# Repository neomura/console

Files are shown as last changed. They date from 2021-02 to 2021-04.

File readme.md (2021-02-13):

# neomura/console

Circuit design and shell for home console.

| Link | Description |
| --- | --- |
| [License](./license.md) | MIT License. |
| [Circuit Design](./circuit-design/readme.md) | KiCad files and assembly instructions for the PCB. |
| [Shell](./shell/readme.md) | OpenSCAD modules for the outer shell. |

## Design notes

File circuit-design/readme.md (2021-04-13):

# [neomura/console](../readme.md)/Circuit Design

| Link | Description |
| --- | --- |
| [console.pro](./console.pro) | KiCAD project. |
| [console.sch](./console.sch) | KiCAD schematic. |
| [console.kicad_pcb](./console.kicad_pcb) | KiCAD PCB layout. |
| [Neomura_Console.lib](./Neomura_Console.lib) | KiCAD symbol for pad connector. |
| [Neomura_Console.pretty/BS800L.kicad_mod](./Neomura_Console.pretty/BS800L.kicad_mod) | KiCAD footprint for power/reset switch. |
| [Neomura_Console.pretty/Pad_Connector.kicad_mod](./Neomura_Console.pretty/Pad_Connector.kicad_mod) | KiCAD footprint for pad connector. |
| [Neomura_Console.pretty/RCA_Jack.kicad_mod](./Neomura_Console.pretty/RCA_Jack.kicad_mod) | KiCAD footprint for RCA jack. |

## Bill of materials

Links are included for reference only and are not endorsements.

| Reference | Description | Model No. | Link |
| --- | --- | --- | --- |
| J1 | Cartridge connector (1x15 2.54mm female pin socket) | Unknown | [https://www.aliexpress.com/item/33021040052.html?spm=a2g0s.9042311.0.0.65b74c4dMpBmdG](https://www.aliexpress.com/item/33021040052.html?spm=a2g0s.9042311.0.0.65b74c4dMpBmdG) |
| J2 | 2.1mm PCB-mount DC power jack | Unknown | [https://www.bitsbox.co.uk/index.php?main_page=product_info&cPath=225_232&products_id=1697](https://www.bitsbox.co.uk/index.php?main_page=product_info&cPath=225_232&products_id=1697) |
| J3 | Yellow PCB-mount RCA jack | AV-8.4-5 (yellow) | [https://www.aliexpress.com/item/4000661766823.html?spm=a2g0s.9042311.0.0.102e4c4dDtr353](https://www.aliexpress.com/item/4000661766823.html?spm=a2g0s.9042311.0.0.102e4c4dDtr353) |
| J4 | White PCB-mount RCA jack | AV-8.4-5 (white)  | [https://www.aliexpress.com/item/4000661766823.html?spm=a2g0s.9042311.0.0.102e4c4dDtr353](https://www.aliexpress.com/item/4000661766823.html?spm=a2g0s.9042311.0.0.102e4c4dDtr353) |
| J5 | Red PCB-mount RCA jack | AV-8.4-5 (red) | [https://www.aliexpress.com/item/4000661766823.html?spm=a2g0s.9042311.0.0.102e4c4dDtr353](https://www.aliexpress.com/item/4000661766823.html?spm=a2g0s.9042311.0.0.102e4c4dDtr353) |
| J6/J7/J8/J9 | 90-degree SNES controller jack | Unknown | [https://www.aliexpress.com/item/32828768824.html?spm=a2g0s.9042311.0.0.102e4c4dh9cZSi](https://www.aliexpress.com/item/32828768824.html?spm=a2g0s.9042311.0.0.102e4c4dh9cZSi) |
| SW1 | 8x8mm latching button | BS800L | [https://www.amazon.co.uk/gp/product/B01KJHR3W6/ref=ppx_yo_dt_b_asin_title_o01_s00?ie=UTF8&psc=1](https://www.amazon.co.uk/gp/product/B01KJHR3W6/ref=ppx_yo_dt_b_asin_title_o01_s00?ie=UTF8&psc=1) |
| SW2 | 8x8mm momentary button | Unknown | [https://www.amazon.co.uk/gp/product/B00TX5K07G/ref=ppx_yo_dt_b_asin_title_o00_s00?ie=UTF8&psc=1](https://www.amazon.co.uk/gp/product/B00TX5K07G/ref=ppx_yo_dt_b_asin_title_o00_s00?ie=UTF8&psc=1) |
| R1 | 4.7K resistor | Unknown | [https://www.bitsbox.co.uk/index.php?main_page=product_info&cPath=83_84_85&products_id=2561](https://www.bitsbox.co.uk/index.php?main_page=product_info&cPath=83_84_85&products_id=2561) |
| D1 | Green 5x2x8 rectangular LED | Unknown | [https://www.bitsbox.co.uk/index.php?main_page=product_info&cPath=172_177&products_id=1343](https://www.bitsbox.co.uk/index.php?main_page=product_info&cPath=172_177&products_id=1343) |

A USB A to 2.1mm DC 5V cable such as [https://www.amazon.co.uk/gp/product/B07SR1SGXQ/ref=ppx_yo_dt_b_asin_title_o05_s00?ie=UTF8&psc=1](https://www.amazon.co.uk/gp/product/B07SR1SGXQ/ref=ppx_yo_dt_b_asin_title_o05_s00?ie=UTF8&psc=1) can be used to power the console from a USB power supply.

9.5x4mm self-adhestive feet such as [https://www.bitsbox.co.uk/index.php?main_page=product_info&cPath=185_190&products_id=1418](https://www.bitsbox.co.uk/index.php?main_page=product_info&cPath=185_190&products_id=1418) can be applied to the pockets in the unside of the shell.

### Possible substitutions

#### SW2

SW2 has identical external dimensions to SW1.  It is possible to convert a BS800L to a momentary switch as the momentary variant appears to be somewhat uncommon:

- Use a spudger or pair of tweasers to prise the tabs on opposite sides away and lift the top half of the body away - these tabs are usually white if the bottom half is black or vice versa.
- The blue plunger should now lift out.  Note that there is a small spring underneath it, and a metal contact on either side of it.  These may fall off.
- At the bottom of the bottom half of the body is a small piece of bent wire which is responsible for the latching motion (you can see this through the square cutout in the bottom of the switch).  You should be able to remove this using tweasers.
- Replace the blue plunger, putting the spring back in and pressing the metal contacts back on if they fell off.
- Replace the top half of the body.  The tabs should click back into place.

The button should now press like before, but not latch.  You can check that the switch still works using a multimeter, looking from the bottom:

```
.-----.
|1 3 2|
|   []|
|6 4 5|
'-----'
```

When the switch **is not** pressed, leads 1 and 3, and 6 and 4 **should** be connected.  Leads 3 and 2, and 4 and 5 **should not** be connected.

When the switch **is** pressed, leads 3 and 2, and 4 and 5 **should** be connected.  Leads 1 and 3, and 6 and 4 **should not** be connected.

SW2 could also be omitted entirely at the cost of losing reset functionality (removal of the hole in the top half of the shell is recommended if this is done).

#### D1

The LED can be replaced or omitted entirely - just ensure that R1 is adjusted (or omitted) as appropriate.  Removal of the hole in the top half of the shell is recommended if the LED is omitted.

## Assembly instructions

- Solder R1 and J1, and clip leads.  Ensure that J1's underside is flat against the PCB (no gap, and upright) otherwise the cartridge may not fit.
- Place the top half of the shell upside down.
- Place J2, J3, J4, J5, J6, J7, J8, J9 and D1 into their respective cavities in the top half of the shell.
- Place the PCB logo side down onto the leads of the placed components.
- Solder J2, J3, J4, J5, J6, J7, J8, J9 and D1, and clip leads.
- Press-fit the bottom half of the shell in place.

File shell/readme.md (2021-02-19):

# [neomura/console](../readme.md)/Shell

| Link | Description |
| --- | --- |
| [bottom.scad](./bottom.scad) | OpenSCAD model for the bottom half of the shell. |
| [button-measurements.scad](./button-measurements.scad) | OpenSCAD module describing buttons. |
| [dc-jack-measurements.scad](./dc-jack-measurements.scad) | OpenSCAD module describing DC jacks. |
| [foot-measurements.scad](./foot-measurements.scad) | OpenSCAD module describing feet. |
| [label-measurements.scad](./label-measurements.scad) | OpenSCAD module describing labels. |
| [led-measurements.scad](./led-measurements.scad) | OpenSCAD module describing LEDs. |
| [outer-measurements.scad](./ouoter-measurements.scad) | OpenSCAD module describing the outer perimeter. |
| [pad-connector-measurements.scad](./pad-connector-measurements.scad) | OpenSCAD module describing pad connectors. |
| [pcb-measurements.scad](./pcb-measurements.scad) | OpenSCAD module describing the PCB. |
| [peg-measurements.scad](./peg-measurements.scad) | OpenSCAD module describing retaining pegs. |
| [power-button.scad](./power-button.scad) | OpenSCAD model for the power button. |
| [rca-jack-measurements.scad](./rca-jack-measurements.scad) | OpenSCAD module describing RCA jacks. |
| [reset-button.scad](./reset-button.scad) | OpenSCAD model for the reset button. |
| [resistor-measurements.scad](./rca-jack-measurements.scad) | OpenSCAD module describing resistors. |
| [top.scad](./top.scad) | OpenSCAD model for the top half of the shell. |
| [unsplit.scad](./unsplit.scad) | OpenSCAD module for the shell as a whole, unsplit into top and bottom halves. |

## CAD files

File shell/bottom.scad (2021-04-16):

use <../submodules/neomura/cartridge/measurements.scad>;
use <../submodules/neomura/cartridge/slot/vertical/solder-joint-cutout.scad>;
use <pad-connector-measurements.scad>;
use <pcb-measurements.scad>;
use <outer-measurements.scad>;
use <rca-jack-measurements.scad>;
use <unsplit.scad>;
use <resistor-measurements.scad>;
use <led-measurements.scad>;
use <dc-jack-measurements.scad>;
use <button-measurements.scad>;
use <foot-measurements.scad>;
use <label-measurements.scad>;
use <slot-measurements.scad>;

intersection() {
  difference() {
    // The main block.
    translate([
      console_outer_left(),
      console_outer_near(),
      0,
    ]) {
      cube([
        - console_outer_left() + console_outer_right(),
        - console_outer_near() + console_outer_far(),
        console_pcb_top() + console_rca_jack_position(),
      ]);
    };

    // Cutout for PCB.
    translate([
      console_pcb_left() - cartridge_pcb_tolerance(),
      console_pcb_near() - cartridge_pcb_tolerance(),
      console_pcb_bottom(),
    ]) {
      cube([
        cartridge_pcb_tolerance() - console_pcb_left() + console_pcb_right() + cartridge_pcb_tolerance(),
        cartridge_pcb_tolerance() - console_pcb_near() + console_pcb_far() + cartridge_pcb_tolerance(),
        cartridge_pcb_tolerance() + cartridge_pcb_thickness() + cartridge_pcb_tolerance() + console_pcb_to_top(),
      ]);
    };

    // Cutouts for feet.
    linear_extrude(console_foot_embed()) {
      translate([
        console_outer_left() + console_foot_margin() + console_foot_diameter() / 2,
        console_outer_near() + console_foot_margin() + console_foot_diameter() / 2,
      ]) {
        circle(
          d = console_foot_tolerance() + console_foot_diameter() + console_foot_tolerance(),
          $fn = console_foot_sides()
        );
      };

      translate([
        console_outer_right() - console_foot_margin() - console_foot_diameter() / 2,
        console_outer_near() + console_foot_margin() + console_foot_diameter() / 2,
      ]) {
        circle(
          d = console_foot_tolerance() + console_foot_diameter() + console_foot_tolerance(),
          $fn = console_foot_sides()
        );
      };

      translate([
        console_outer_left() + console_foot_margin() + console_foot_diameter() / 2,
        console_outer_far() - console_foot_margin() - console_foot_diameter() / 2,
      ]) {
        circle(
          d = console_foot_tolerance() + console_foot_diameter() + console_foot_tolerance(),
          $fn = console_foot_sides()
        );
      };

      translate([
        console_outer_right() - console_foot_margin() - console_foot_diameter() / 2,
        console_outer_far() - console_foot_margin() - console_foot_diameter() / 2,
      ]) {
        circle(
          d = console_foot_tolerance() + console_foot_diameter() + console_foot_tolerance(),
          $fn = console_foot_sides()
        );
      };
    };

    // Solder joint cutouts.
    translate([
      0,
      0,
      console_pcb_bottom() - console_pcb_to_bottom(),
    ]) {
      linear_extrude(console_pcb_to_bottom() + cartridge_pcb_tolerance() + cartridge_pcb_thickness()) {
        translate([
          console_slot_x(),
          console_slot_y(),
        ]) {
          cartridge_slot_vertical_solder_joint_cutout();
        };

        for (pad_position = console_pad_connector_positions()) {
          translate([
            pad_position[0],
            pad_position[1],
          ]) {
            rotate(pad_position[2]) {
              translate([0, cartridge_wall_thickness(), 0]) {
                translate([
                  - cartridge_loose_fit_tolerance() + console_pad_connector_terminals_width() / -2,
                  - console_pad_connector_terminals_length() - console_pad_connector_length() - cartridge_loose_fit_tolerance(),
                ]) {
                  square([
                    cartridge_loose_fit_tolerance() + console_pad_connector_terminals_width() + cartridge_loose_fit_tolerance(),
                    console_pad_connector_terminals_length(),
                  ]);
                };

                translate([
                  console_pad_connector_peg_spacing() / -2,
                  - console_pad_connector_peg_inset(),
                ]) {
                  circle(
                    d = console_pad_connector_peg_diameter(),
                    $fn = console_pad_connector_peg_sides()
                  );
                };

                translate([
                  console_pad_connector_peg_spacing() / 2,
                  - console_pad_connector_peg_inset(),
                ]) {
                  circle(
                    d = console_pad_connector_peg_diameter(),
                    $fn = console_pad_connector_peg_sides()
                  );
                };
              };
            };
          };
        };

        for (button_position = console_button_positions()) {
          translate([button_position[0], button_position[1]]) {
            rotate(button_position[2]) {
              translate([
                - (cartridge_pad_spacing() / 2 + console_button_body_width() + cartridge_pad_spacing() / 2) / 2,
                - (cartridge_pad_spacing() / 2 + console_button_body_length() + cartridge_pad_spacing() / 2) / 2,
              ]) {
                square([
                  cartridge_pad_spacing() / 2 + console_button_body_width() + cartridge_pad_spacing() / 2,
                  cartridge_pad_spacing() / 2 + console_button_body_length() + cartridge_pad_spacing() / 2,
                ]);
              };
            };
          };
        };

        for (led_position = console_led_positions()) {
          translate([led_position[0], led_position[1]]) {
            rotate(led_position[2]) {
              translate([
                - console_led_width() / 2,
                - console_led_length() / 2,
              ]) {
                square([console_led_width(), console_led_length()]);
              };
            };
          };
        };

        for (resistor_position = console_resistor_positions()) {
          translate([resistor_position[0], resistor_position[1]]) {
            rotate(resistor_position[2]) {
              translate([
                - console_resistor_width() / 2,
                - console_resistor_length() / 2,
              ]) {
                square([
                  console_resistor_width(),
                  console_resistor_length(),
                ]);
              };
            };
          };
        };

        for (dc_jack_position = console_dc_jack_positions()) {
          translate([dc_jack_position[0], dc_jack_position[1]]) {
            rotate(dc_jack_position[2]) {
              for (pad_position = console_dc_jack_pad_positions()) {
                translate(pad_position) {
                  square(console_dc_jack_pad_diameter(), center = true);
                };
              };
            };
          };
        };

        for (rca_jack_position = console_rca_jack_positions()) {
          translate([rca_jack_position[0], rca_jack_position[1]]) {
            rotate(rca_jack_position[2]) {
              translate([
                - cartridge_loose_fit_tolerance() -console_rca_jack_body_width() / 2,
                -console_rca_jack_pocket_length(),
              ]) {
                square([
                  cartridge_loose_fit_tolerance() + console_rca_jack_body_width() + cartridge_loose_fit_tolerance(),
                  console_rca_jack_pocket_length() + cartridge_loose_fit_tolerance(),
                ]);
              };

              for (pad_position = console_rca_jack_pad_positions()) {
                translate(pad_position) {
                  square(console_rca_jack_pad_diameter(), center = true);
                };
              };
            };
          };
        };
      };
    };

    // Label.
    linear_extrude(cartridge_engraving_depth()) {
      hull() {
        translate([
          console_label_width() / 2 - console_label_radius(),
          (console_outer_near() + console_outer_far() + console_label_height()) / 2 - console_label_radius(),
        ]) {
          circle(
            r = console_label_radius(),
            $fn = cartridge_engraving_sides()
          );
        };

        translate([
          - console_label_width() / 2 + console_label_radius(),
          (console_outer_near() + console_outer_far() + console_label_height()) / 2 - console_label_radius(),
        ]) {
          circle(
            r = console_label_radius(),
            $fn = cartridge_engraving_sides()
          );
        };

        translate([
          console_label_width() / 2 - console_label_radius(),
          (console_outer_near() + console_outer_far() - console_label_height()) / 2 + console_label_radius(),
        ]) {
          circle(
            r = console_label_radius(),
            $fn = cartridge_engraving_sides()
          );
        };
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

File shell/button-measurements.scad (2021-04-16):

use <../submodules/neomura/cartridge/measurements.scad>;
use <pad-connector-measurements.scad>;

function console_button_throw() = 2.3;

function console_button_stub_width() = 3 + cartridge_loose_fit_tolerance() * 2;
function console_button_stub_length() = 2 + cartridge_loose_fit_tolerance() * 2;
function console_button_stub_height() = 2.5 + cartridge_loose_fit_tolerance();

function console_button_pixel_size() = cartridge_logo_height() / 7;
function console_button_pixel_push() = 0.075;

function console_button_length() = console_button_pixel_size() + cartridge_engraving_radius() + cartridge_logo_height() + cartridge_engraving_radius() + console_button_pixel_size();
function console_button_width() = console_button_length();
function console_button_height() = console_button_stub_height() + cartridge_wall_thickness() + console_button_throw();

function console_button_lip_width() = cartridge_wall_thickness();
function console_button_lip_height() = cartridge_wall_thickness();

function console_button_body_width() = 8.125;
function console_button_body_length() = 8.125;
function console_button_body_height() = 8;

function console_button_tolerance() = 0.3;

function console_button_positions() = [
  [
    console_pad_connector_positions()[0][0],
    0,
    0,
  ],
  [
    console_pad_connector_positions()[3][0],
    0,
    0,
  ],
];

module console_button() {
  difference() {
      linear_extrude(console_button_height()) {
        hull() {
          translate([
            console_button_width() / 2 - console_button_pixel_size() - cartridge_engraving_radius(),
            console_button_length() / 2 - console_button_pixel_size() - cartridge_engraving_radius(),
          ]) {
            circle(
              r = cartridge_engraving_radius() + console_button_pixel_size(),
              $fn = cartridge_engraving_sides()
            );
          };

          translate([
            console_button_width() / 2 - console_button_pixel_size() - cartridge_engraving_radius(),
            - console_button_length() / 2 + console_button_pixel_size() + cartridge_engraving_radius(),
          ]) {
            circle(
              r = cartridge_engraving_radius() + console_button_pixel_size(),
              $fn = cartridge_engraving_sides()
            );
          };

          translate([
            - console_button_width() / 2 + console_button_pixel_size() + cartridge_engraving_radius(),
            console_button_length() / 2 - console_button_pixel_size() - cartridge_engraving_radius(),
          ]) {
            circle(
              r = cartridge_engraving_radius() + console_button_pixel_size(),
              $fn = cartridge_engraving_sides()
            );
          };

          translate([
            - console_button_width() / 2 + console_button_pixel_size() + cartridge_engraving_radius(),
            - console_button_length() / 2 + console_button_pixel_size() + cartridge_engraving_radius(),
          ]) {
            circle(
              r = cartridge_engraving_radius() + console_button_pixel_size(),
              $fn = cartridge_engraving_sides()
            );
          };
        };
      };

    translate([
      0,
      0,
      console_button_height() - cartridge_engraving_depth(),
    ]) {
      linear_extrude(cartridge_engraving_depth()) {
        difference() {
          hull() {
            translate([
              console_button_width() / 2 - console_button_pixel_size() - cartridge_engraving_radius(),
              console_button_length() / 2 - console_button_pixel_size() - cartridge_engraving_radius(),
            ]) {
              circle(
                r = cartridge_engraving_radius(),
                $fn = cartridge_engraving_sides()
              );
            };

            translate([
              console_button_width() / 2 - console_button_pixel_size() - cartridge_engraving_radius(),
              - console_button_length() / 2 + console_button_pixel_size() + cartridge_engraving_radius(),
            ]) {
              circle(
                r = cartridge_engraving_radius(),
                $fn = cartridge_engraving_sides()
              );
            };

            translate([
              - console_button_width() / 2 + console_button_pixel_size() + cartridge_engraving_radius(),
              console_button_length() / 2 - console_button_pixel_size() - cartridge_engraving_radius(),
            ]) {
              circle(
                r = cartridge_engraving_radius(),
                $fn = cartridge_engraving_sides()
              );
            };

            translate([
              - console_button_width() / 2 + console_button_pixel_size() + cartridge_engraving_radius(),
              - console_button_length() / 2 + console_button_pixel_size() + cartridge_engraving_radius(),
            ]) {
              circle(
                r = cartridge_engraving_radius(),
                $fn = cartridge_engraving_sides()
              );
            };
          };

          children();
        };
      };
    };

    translate([
      console_button_stub_width() / -2,
      console_button_stub_length() / -2,
      0,
    ]) {
      cube([
        console_button_stub_width(),
        console_button_stub_length(),
        console_button_stub_height(),
      ]);
    };
  };
};

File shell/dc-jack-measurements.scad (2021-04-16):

use <../submodules/neomura/cartridge/measurements.scad>;
use <pad-connector-measurements.scad>;

function console_dc_jack_body_width() = 9;
function console_dc_jack_body_length() = 13.8;
function console_dc_jack_body_height() = 10.2;

function console_dc_jack_face_height() = 11;
function console_dc_jack_face_thickness() = 2.9;

function console_dc_jack_diameter() = 8.35;
function console_dc_jack_position() = 6.6;
function console_dc_jack_sides() = 48;

function console_dc_jack_positions() = [
  [
    console_pad_connector_positions()[0][0],
    23.0825,
    180,
  ],
];

function console_dc_jack_pad_diameter() = 3.5;
function console_dc_jack_pad_positions() = [
  [0, 7.7],
  [4.75, 10.72],
  [0, 13.7],
];

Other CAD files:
shell/foot-measurements.scad
shell/foot.scad
shell/label-measurements.scad
shell/led-measurements.scad
shell/outer-measurements.scad
shell/pad-connector-measurements.scad
shell/pcb-measurements.scad
shell/power-button.scad
shell/rca-jack-measurements.scad
shell/reset-button.scad
shell/resistor-measurements.scad
shell/slot-measurements.scad
shell/top.scad
shell/unsplit.scad

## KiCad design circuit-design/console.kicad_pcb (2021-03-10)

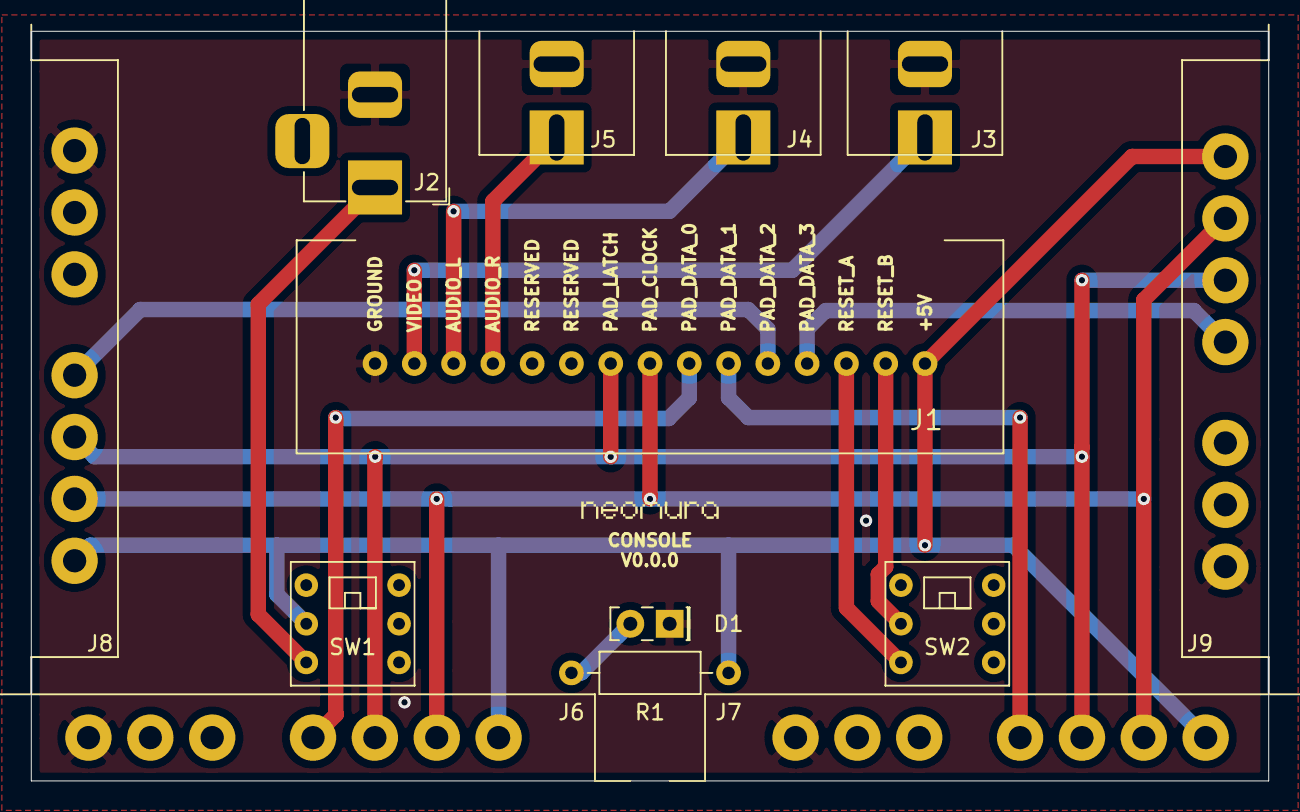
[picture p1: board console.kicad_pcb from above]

Board: 2 copper layers, 80.0 x 48.5 mm, 14 parts (0 on the bottom side), 15 nets.

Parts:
D1: LED; LED_Rectangular_W5.0mm_H2.0mm
J1: CARTRIDGE; Slot-Vertical
J2: POWER; BarrelJack_Horizontal
J3: VIDEO (YELLOW); RCA_Jack
J4: AUDIO (WHITE); RCA_Jack
J5: AUDIO (RED); RCA_Jack
J6: PAD 0; Pad_Connector
J7: PAD 1; Pad_Connector
J8: PAD 2; Pad_Connector
J9: PAD 3; Pad_Connector
R1: 240R; R_Axial_DIN0207_L6.3mm_D2.5mm_P10.16mm_Horizontal
Ref**: Val**; Front-Silkscreen
SW1: POWER_SW; BS800L
SW2: RESET_SW; BS800L

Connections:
+5V: J1.15, J6.1, J7.1, J8.1, J9.1, R1.2, SW1.6
AUDIO_L: J1.3, J4.1
AUDIO_R: J1.4, J5.1
GND: D1.1, J1.1, J2.2, J3.2, J4.2, J5.2, J6.7, J7.7, J8.7, J9.7
unnamed: D1.2, R1.1
unnamed: J2.1, SW1.5
PAD_CLOCK: J1.8, J6.2, J7.2, J8.2, J9.2
PAD_DATA_0: J1.9, J6.4
PAD_DATA_1: J1.10, J7.4
PAD_DATA_2: J1.11, J8.4
PAD_DATA_3: J1.12, J9.4
PAD_LATCH: J1.7, J6.3, J7.3, J8.3, J9.3
RESET_A: J1.13, SW2.5
RESET_B: J1.14, SW2.6
VIDEO: J1.2, J3.1

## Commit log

2021-02-13 Add PCB.
    [console.kicad_pcb, console.sch]
2021-02-13 Fix sikscreen positioning.
    [console.kicad_pcb]
2021-02-13 Update export settings.
    [console.kicad_pcb]
2021-02-13 Add missing audio via.
    [console.kicad_pcb]
2021-02-13 Add initial drafts of power/reset buttons.
    [button-measurements.scad, power-button.scad, reset-button.scad]
2021-02-13 Correct measurements.
    [button-measurements.scad]
2021-02-13 Rotate buttons.
    [button-measurements.scad]
2021-02-13 Fix incorect sizing of buttons.
    [button-measurements.scad]
2021-02-13 Add a surround to guide button caps down the button.
    [button-measurements.scad]
2021-02-13 Build most of the shell.
    [button-measurements.scad, dc-jack-measurements.scad, led-measurements.scad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]
2021-02-13 Fix alignment of DC jack and remove need for slots on back edge.
    [console.kicad_pcb]
2021-02-14 Turn unsplit into a module.
    [unsplit.scad]
2021-02-15 Fix regression caused by submodule update.
    [unsplit.scad]
2021-02-16 Increase DC jack sides.
    [dc-jack-measurements.scad]
2021-02-16 Add foot.
    [foot-measurements.scad, foot.scad]
2021-02-16 Add missing cutouts for pad connector terminals.
    [unsplit.scad]
2021-02-16 Make room for feet.
    [pcb-measurements.scad]
2021-02-16 Add module for drawing a badge along the edge of the console.
    [outer-measurements.scad]
2021-02-16 Fix cutaway for terminals being twice intended size.
    [unsplit.scad]
2021-02-16 Slightly enlarge DC jack.
    [dc-jack-measurements.scad]
2021-02-16 Define pad positions for DC jack.
    [dc-jack-measurements.scad]
2021-02-16 Slightly enlarge RCA jacks.
    [rca-jack-measurements.scad]
2021-02-19 Redesign to support new cartridge connector.
    [button-measurements.scad, console.kicad_pcb, console.sch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]
2021-02-19 Slightly increase pad connector height.
    [pad-connector-measurements.scad]
2021-02-19 Redesign feet to use off the shelf components.
    [foot-measurements.scad]
2021-02-19 Add dimensions for labels.
    [label-measurements.scad]
2021-02-19 Increase button tolerance.
    [button-measurements.scad, unsplit.scad]
2021-02-19 Rotate badges.
    [outer-measurements.scad]
2021-02-19 Add measurements for retaining pegs.
    [peg-measurements.scad]
2021-02-19 Adjust RCA jack position.
    [rca-jack-measurements.scad]
2021-02-19 Define locations of bottom pockets required by RCA jacks.
    [rca-jack-measurements.scad]
2021-02-19 Update readme.
    [bottom.scad, top.scad]
2021-02-20 Remove unnecessary via.
    [console.kicad_pcb]
2021-02-20 Update BOM.
2021-03-10 Final revisions.
    [console.kicad_pcb]
2021-03-21 Fix the LED being offset.
    [unsplit.scad]
2021-03-21 Add version badges.
    [bottom.scad, top.scad]
2021-03-21 Increase the sizes of buttons and LEDs for a better fit.
    [button-measurements.scad, led-measurements.scad]
2021-03-23 Reduce overhang.
    [button-measurements.scad]
2021-03-27 Reduce peg height. This makes them less likely to break without losing any friction fit quality.
    [peg-measurements.scad]
2021-04-13 Decrease LED current.
    [console.sch]
2021-04-16 Begin redesigning to take NES controllers.
    [bottom.scad, button-measurements.scad, dc-jack-measurements.scad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]
2021-04-16 Reorder jacks.
    [dc-jack-measurements.scad, rca-jack-measurements.scad]
2021-04-16 Continue redesign.
    [bottom.scad, button-measurements.scad, dc-jack-measurements.scad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]
2021-04-16 Redesign buttons.
    [button-measurements.scad, power-button.scad, reset-button.scad]
